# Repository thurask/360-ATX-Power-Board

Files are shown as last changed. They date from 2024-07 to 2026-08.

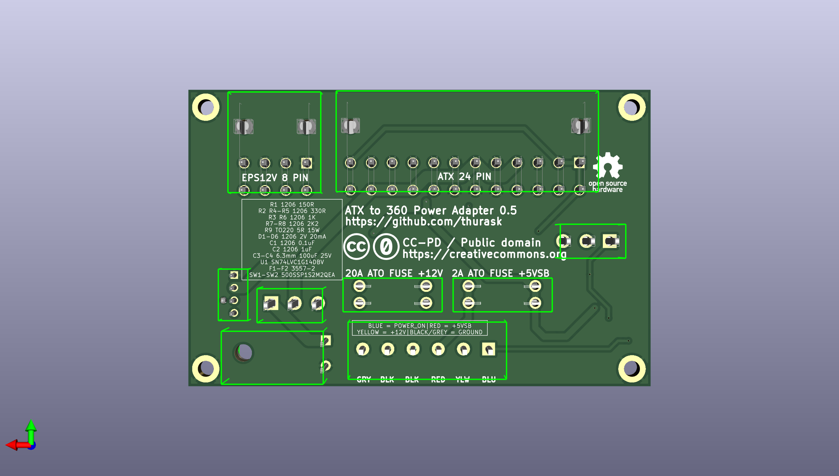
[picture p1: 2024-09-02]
360_atx_power_board_2.png

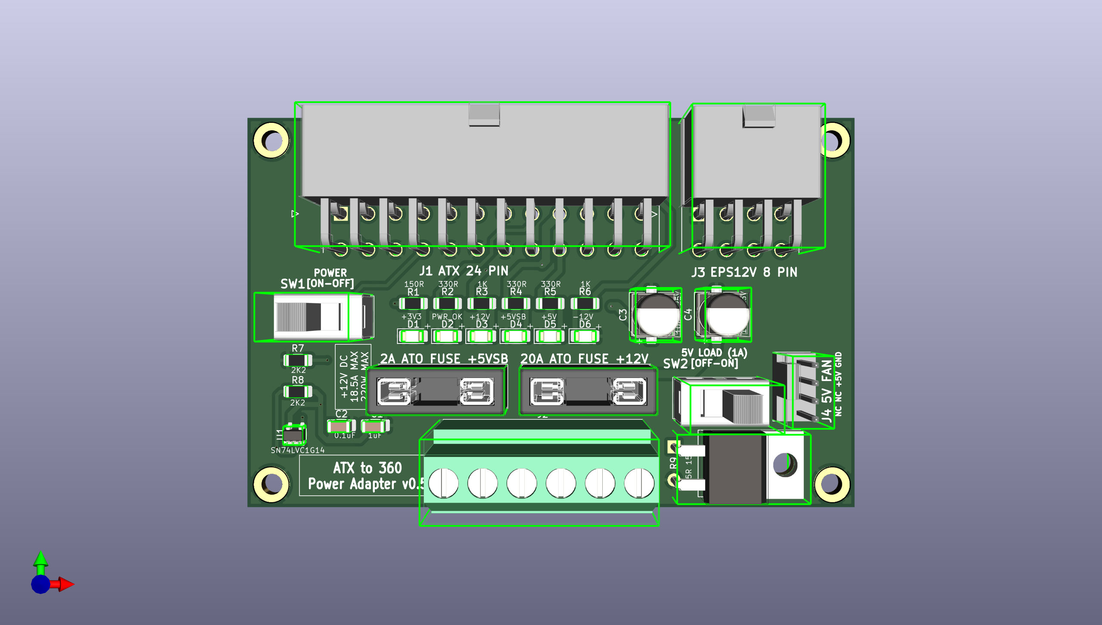
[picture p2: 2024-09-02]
360_atx_power_board.png

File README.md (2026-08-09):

# 360-ATX-Power-Board
ATX to Xbox power adapter board for Xbox 360

360_atx_power_board

# Rationale
Powering an Xbox 360 without using the original antique brick, instead using a modern, quiet, smaller, efficient ATX power supply. Also doing the same without just having components and wire connections dangling in air or stuck on breadboard.

# Compatibility
Any Xbox 360, provided you have some way of getting power from the screw terminals into the console itself. I tested this with a Xenon. The most power-hungry model (Xenon) came with a 203W power adapter, so a 300W or higher ATX PSU should power without running into current limits.

This theoretically could work with an Xbox One but I don't have one to test.

# Prerequisites
- An ATX power supply capable of supplying at least 220W over 12V
- The power cable from an Xbox 360 power brick or compatible replacement
- Fuses (automotive style ATO fuses), 2A and 20A

# Instructions
1. Desolder or otherwise harvest the device-side power cable (i.e. not the wall end) from an Xbox 360 power brick or compatible; I think you can get the connector itself on Aliexpress and fabricate your own cable with thick enough wiring to handle the current
2. Assemble PCB, including installing the fuses
3. Connect your power supply's 24 pin ATX connector and the 4/8 pin EPS12V connector to the PCB; the absolute maximum power draw for 20 pin ATX and 4 pin EPS12V is just barely enough (20A) to fully supply the most power-hungry Xbox, so ideally plug in 24 pins and 8 pins respectively
4. Connect the Xbox 360 power cable to screw terminal J2; wire colors should match markings on PCB silkscreen
   -   If you harvested a cable from a power brick, consider soldering appropriate gauge short extensions to each connector with solder seal connectors, and then crimping ferrules on the other end of the extensions so that it connects better to the screw terminals
5. Connect the other end of the Xbox 360 power cable to your console
6. Turn on your power supply; +5VSB LED (if installed) should light up
7. Set switch SW1 (if installed) to on
8. Turn on Xbox 360; all LEDs should light up, as should your Xbox

# Building the PCB
Import project files into KiCad 10 and export to your PCB manufacturing service of choice, or just use the files in the grbl subfolder. It's a four layer PCB and it'll carry quite a bit of current, so I recommend thicker than default copper.

# BOM
- Connectors
  - Input
    - J1: 24-pin ATX connector, Molex 39-30-1240 or compatible
    - J3: 8-pin EPS12V connector, Molex 39-30-1080 or compatible
  - Output
    - J2: Phoenix Contact MKDS 3/ 6-5,08 / 1905201 or any compatible 6 hole screw terminal that can handle maximum power draw (>=20A)
  - Fan connector
    - If you want to keep things cool there's a 4 pin PC fan plug J4 intended for a 5V fan, Molex 47053-1000 or compatible. Use some slim Noctua 5V fan or something.
- Components
  - Power signaling
    - Required to translate ATX PS_ON# into the 360's power on signal. The other outputs are purely passthrough.
    - R7, R8: 2.2K, 1206
    - U1: Texas Instruments SN74LVC1G14DBVR or compatible part
    - C1: 1uF 1206 25V
    - C2: 0.1uF 1206 25V
  - Switching
    - SW1: E-Switch 500SSP1S2M2QEA or compatible, or just bridge pin 1 and 2 to always have the board active.
  - Fuses
    - F1-F2: Keystone Electronics 3557-2 or compatible. Uses ATO/ATC automotive fuses.
  - Filtering:
    - C3-C4: 100uF 25V electrolytics, 6.3mm x 7.7mm footprint. Würth Elektronik 865080445010 or compatible.
  - Indicators
    - Optional blinkenlights to see if each power rail is working. Install the following resistor-LED pairs:
    - +12V
      - R3: 1K, 1206
      - D3: 20mW LED, 1206  
    - +5V
      - R5: 330R, 1206
      - D5: 20mW LED, 1206  
    - +5VSB
      - R4: 330R, 1206
      - D4: 20mW LED, 1206
    - +3.3V
      - R1: 150R, 1206
      - D1: 20mW LED, 1206
    - -12V
      - R6: 1K, 1206
      - D6: 20mW LED, 1206 (note the reversed orientation compared to the others!)
    - PWR_OK
      - R2: 330R, 1206
      - D2: 20mW LED, 1206
  - 5V Load
    - Since the 360 is almost exclusively 12V load, some PSUs may shut down prematurely due to lack of 5V load. If you have such a PSU or just want to play it safe, install the following to have a 5W (1A) load:
    - SW2: E-Switch 500SSP1S2M2QEA or compatible (or bridge pins 1 and 2 to always have the load active), same part as SW1
    - R9: 5R, TO220, >=15W (ex. Bourns PWR220T-20-5R00F)

# Contributing
Feel free to do what you like with this; build it, change it, fix it, sell it, whatever. If you do make improvements it'd be super cool to make those publicly available.

# License
CC0-1.0

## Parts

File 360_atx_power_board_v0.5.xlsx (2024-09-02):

Item # | *Designator | *Qty | Manufacturer | *Mfg Part # | Description / Value | *Package/Footprint | Type | Your Instructions / Notes
1 | J1 | 1 | Molex | 39-30-1240 | Connector Header Through Hole, Right Angle 24 position 0.165" (4.20mm) | 24POS | THT | 24 pin ATX power connector
2 | J2 | 1 | Phoenix Contact | MKDS 3/ 6-5,08 / 1701144 | 6 Position Wire to Board Terminal Block Horizontal with Board 0.200" (5.08mm) Through Hole | 5POS | THT | Substitutions: CUI TB009-508-06BE; CUI TB010-508-06BE; TE 282841-6; TE 282857-6; Phoenix Contact 1989405; Phoenix Contact 1730544
3 | J3 | 1 | Molex | 39-30-1080 | Connector Header Through Hole, Right Angle 8 position 0.165" (4.20mm) | 8POS | THT | 8 pin EPS12V connector
4 | J4 | 1 | Molex | 47053-1000 | Connector Header Through Hole 4 position 0.100" (2.54mm) | 4POS | THT | 4 pin PC fan connector
5 | U1 | 1 | Texas Instruments | SN74LVC1G14DBVR | Inverter IC 1 Channel Schmitt Trigger SOT-23-5 | SOT-23 | SMD | Subsitutions: Nexperia 74LVC1G14GV-Q100,1 ; Diodes Incorporated 74LVC1G14W5-7 ; onsemi NC7SZ14M5X
6 | R1 | 1 | Yageo | RC1206FR-07150RL | 150 Ohms ±1% 0.25W, 1/4W Chip Resistor 1206 (3216 Metric) Moisture Resistant Thick Film | 1206 | SMD | Substitutions: any 0.25W 1206/3216 resistor with same value
7 | R2, R4-R5 | 3 | Yageo | RC1206JR-07330RL | 330 Ohms ±1% 0.25W, 1/4W Chip Resistor 1206 (3216 Metric) Moisture Resistant Thick Film | 1206 | SMD | Substitutions: any 0.25W 1206/3216 resistor with same value
8 | R3, R6 | 2 | Yageo | RC1206FR-071KL | 1 kOhms ±1% 0.25W, 1/4W Chip Resistor 1206 (3216 Metric) Moisture Resistant Thick Film | 1206 | SMD | Substitutions: any 0.25W 1206/3216 resistor with same value
9 | R7-R8 | 2 | Yageo | RC1206FR-072K2L | 2.2 kOhms ±1% 0.25W, 1/4W Chip Resistor 1206 (3216 Metric) Moisture Resistant Thick Film | 1206 | SMD | Substitutions: any 0.25W 1206/3216 resistor with same value
10 | R9 | 1 | Bourns | PWR220T-20-5R00F | 5 Ohms ±1% 20W Through Hole Resistor TO-220-2, Variant Automotive AEC-Q200, Current Sense, Pulse Withstanding Thick Film | TO-220 | THT | Substitutions: Bourns PWR220T-20-5R00J; Vishay LTO030F5R000FTE3; Caddock MP930-5.00-1%
11 | C1 | 1 | Kemet | C1206C105M3RAC7800 | 1 µF ±10% 25V Ceramic Capacitor X7R 1206 (3216 Metric) | 1206 | SMD | Substitutions: any 25V X7R 1206 ceramic capacitor with same value
12 | C2 | 1 | Kemet | C1206C104K3RAC7800 | 0.1 µF ±10% 25V Ceramic Capacitor X7R 1206 (3216 Metric) | 1206 | SMD | Substitutions: any 25V X7R 1206 ceramic capacitor with same value
13 | C3-C4 | 2 | Wurth Elektronik | 865080445010 | 100 µF 25 V Aluminum Electrolytic Capacitors Radial, Can - SMD 2000 Hrs @ 105°C | 6.3mmx8mm | SMD | Substitutions: Nichicon UWT1E101MCL1GS; Rubycon 25TZV100M6.3X8; Nichicon UCD1V101MCL6GS
14 | D1-D6 | 6 | Wurth Elektronik | 156120VS75000 | Green 573nm LED Indication - Discrete 2V 1206 (3216 Metric) | 1206 | SMD | Substitutions: Lite-On LTST-C150KGKT; Dialight 598-8270-102F; Bivar SM1206GC-IL
15 | F1-F2 | 2 | Keystone Electronics | 3557 | Fuse Block 30 A 500V 1 Circuit Blade Through Hole | 4PIN | THT
16 | SW1-2 | 2 | E-Switch | 500SSP1S2M2QEA | Slide Switches 5A 150VAC or 28VDC On-None-ON SPDT | SPDT | THT | Substitutions: any E-Switch 500SSP1SxM2xEx or 500SSP3SxM2xEx

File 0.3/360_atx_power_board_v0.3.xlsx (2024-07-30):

Item # | *Designator | *Qty | Manufacturer | *Mfg Part # | Description / Value | *Package/Footprint | Type | Your Instructions / Notes
1 | J1 | 1 | Molex | 39-30-1240 | Connector Header Through Hole, Right Angle 24 position 0.165" (4.20mm) | 24POS | THT | 24 pin ATX power connector
2 | J2 | 1 | Phoenix Contact | MKDS 3/ 5-5,08 / 1905201 | 5 Position Wire to Board Terminal Block Horizontal with Board 0.200" (5.08mm) Through Hole | 5POS | THT | Substitutions: CUI TB009-508-05BE; CUI TB010-508-05BE; TE 282841-5; TE 282857-5; Phoenix Contact 1931644; Phoenix Contact 1730531
3 | J3 | 1 | TE | 641737-1 | Connector Header Through Hole, Right Angle 4 position 0.200" (5.08mm) | 4POS | THT | 4 pin "Molex" peripheral connector
4 | J4 | 1 | Molex | 39-30-1080 | Connector Header Through Hole, Right Angle 8 position 0.165" (4.20mm) | 8POS | THT | 8 pin EPS12V connector
5 | J5 | 1 | Molex | 45586-0005 | Connector Header Through Hole, Right Angle 8 position 0.165" (4.20mm) | 8POS | THT | 8 pin PCI Express connector
6 | Q1 | 1 | Diotec Semiconductor | MMBT3904 | Bipolar (BJT) Transistor NPN 40 V 200 mA 300MHz 350 mW Surface Mount SOT-23-3 (TO-236) | SOT-23 | SMD | Substitutions: any other manufacturer's MMBT3904
7 | R1 | 1 | Vishay | RCC1206150RFKEA | 150 Ohms ±1% 0.5W, 1/2W Chip Resistor 1206 (3216 Metric) Automotive AEC-Q200 Thick Film | 1206 | SMD | Substitutions: any 0.5W 1206/3216 resistor with same value
8 | R2, R4, R5 | 3 | Vishay | RCC1206330RFKEA | 330 Ohms ±1% 0.5W, 1/2W Chip Resistor 1206 (3216 Metric) Automotive AEC-Q200 Thick Film | 1206 | SMD | Substitutions: any 0.5W 1206/3216 resistor with same value
9 | R3, R8 | 2 | Vishay | RCC12061K00FKEA | 1 kOhms ±1% 0.5W, 1/2W Chip Resistor 1206 (3216 Metric) Automotive AEC-Q200 Thick Film | 1206 | SMD | Substitutions: any 0.5W 1206/3216 resistor with same value
10 | R6 | 1 | Vishay | RCC1206100KFKEA | 100 kOhms ±1% 0.5W, 1/2W Chip Resistor 1206 (3216 Metric) Automotive AEC-Q200 Thick Film | 1206 | SMD | Substitutions: any 0.5W 1206/3216 resistor with same value
11 | R7 | 1 | Bourns | PWR220T-20-2R50F | 2.5 Ohms ±1% 20W Through Hole Resistor TO-220-2, Variant Automotive AEC-Q200, Current Sense, Pulse Withstanding Thick Film | TO-220 | THT | Substitutions: Bourns PWR220T-35-2R50F; Vishay LTO030F2R500FTE3; Caddock MP930-2.50-1%
12 | D1-D6 | 6 | Wurth Elektronik | 156120VS75000 | Green 573nm LED Indication - Discrete 2V 1206 (3216 Metric) | 1206 | SMD | Substitutions: Lite-On LTST-C150KGKT; Dialight 598-8270-102F; Bivar SM1206GC-IL
13 | SW1-2 | 2 | E-Switch | 500SSP1S2M2QEA | Slide Switches 5A 150VAC or 28VDC On-None-ON SPDT | SPDT | THT | Substitutions: any E-Switch 500SSP1SxM2xEx or 500SSP3SxM2xEx

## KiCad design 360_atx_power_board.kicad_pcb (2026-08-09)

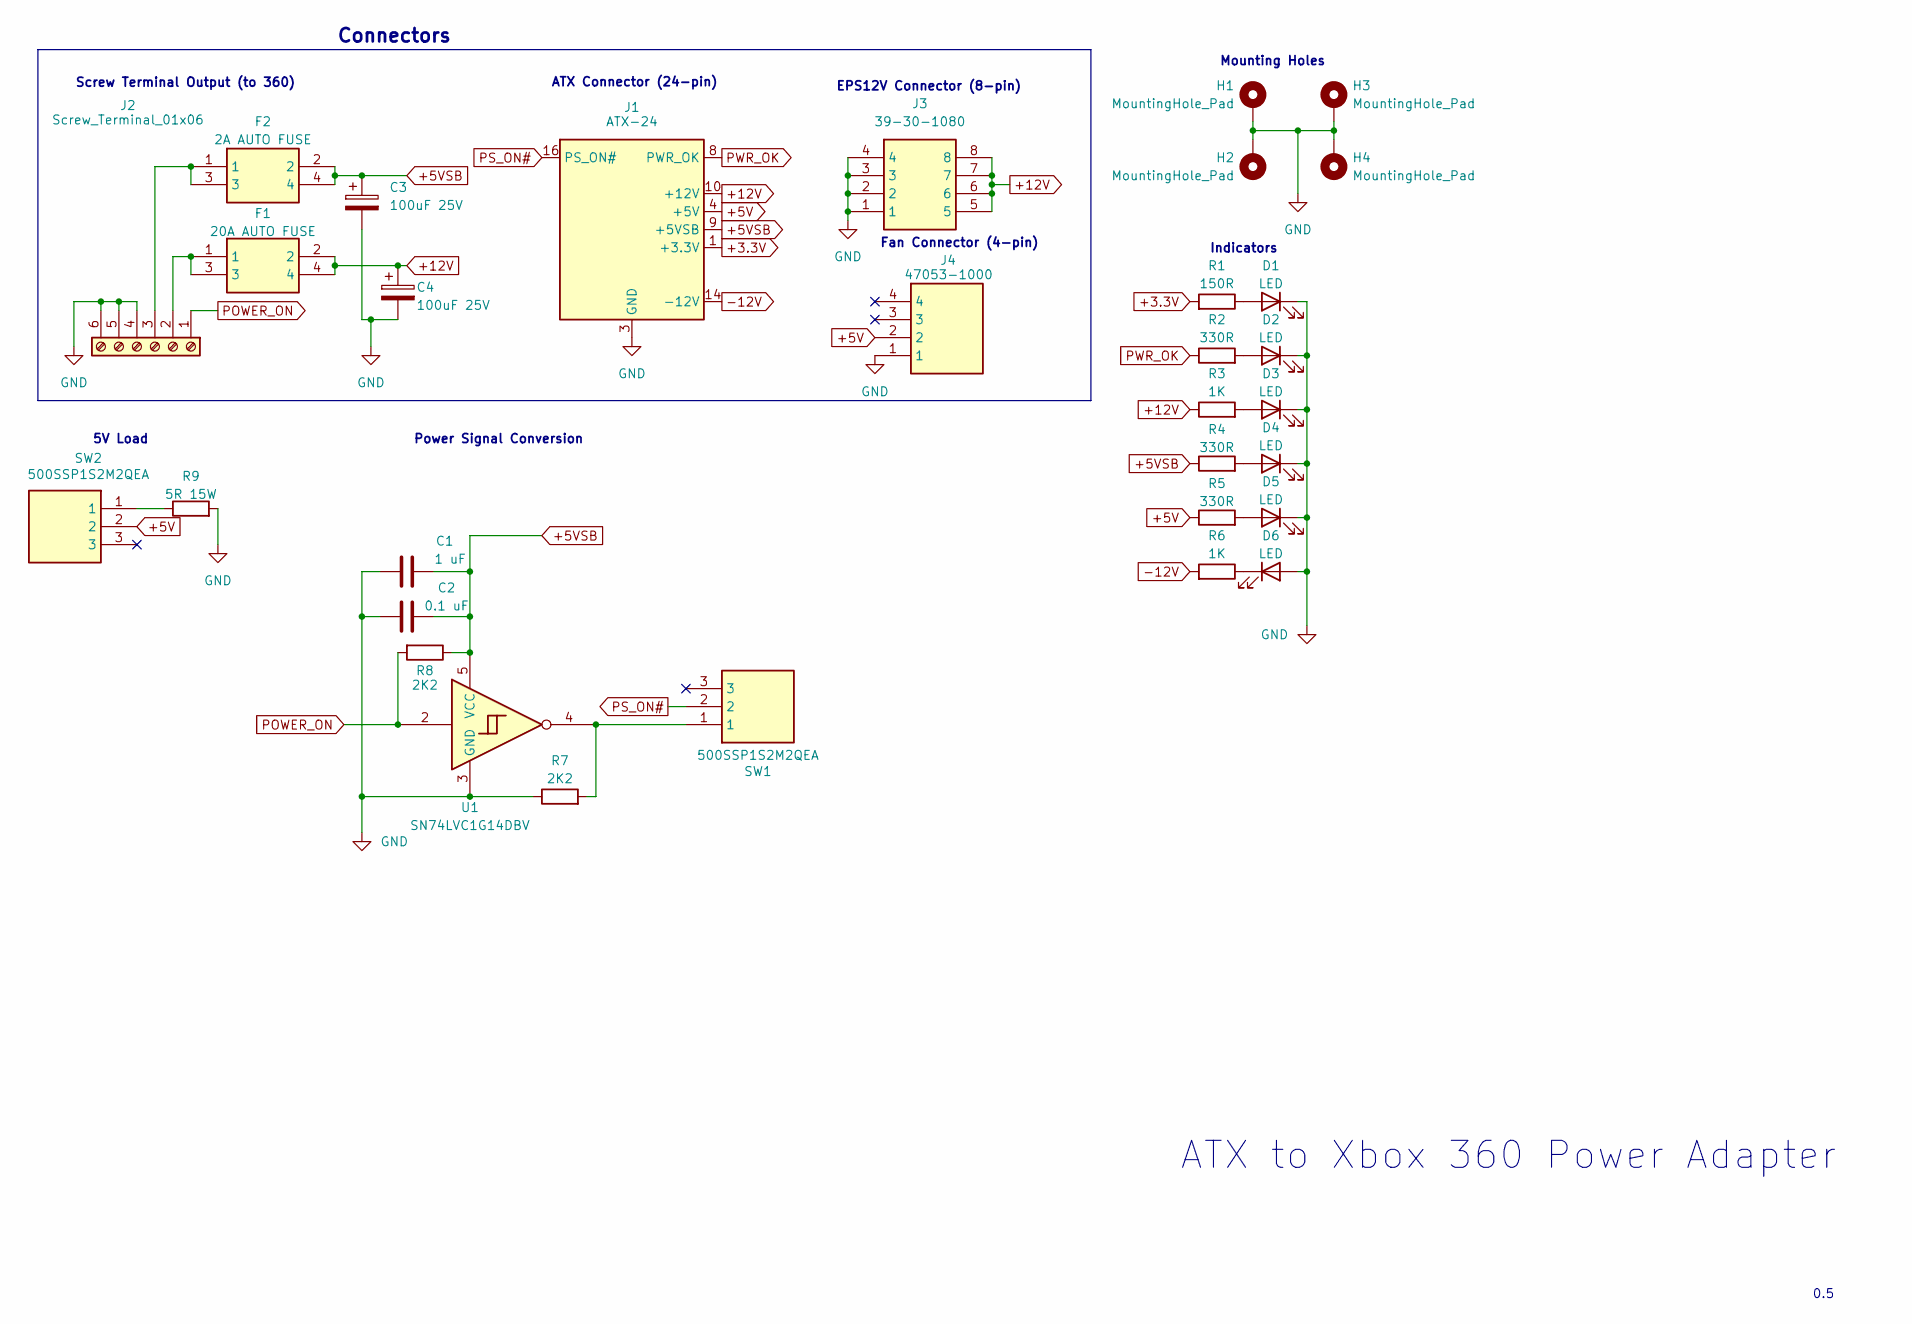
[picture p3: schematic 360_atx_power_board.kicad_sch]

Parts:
C1: 1 uF; C_1206_3216Metric_Pad1.33x1.80mm_HandSolder
C2: 0.1 uF; C_1206_3216Metric_Pad1.33x1.80mm_HandSolder
C3, C4: 100uF 25V; CP_Elec_6.3x7.7
D1, D2, D3, D4, D5, D6: LED; LED_1206_3216Metric_Pad1.42x1.75mm_HandSolder
F1: 20A AUTO FUSE; 3557-2; Manufacturer_Part_Number 3557-2; Mouser Part Number 534-3557-2
F2: 2A AUTO FUSE; 3557-2; Manufacturer_Part_Number 3557-2; Mouser Part Number 534-3557-2
H1, H2, H3, H4: MountingHole_Pad; MountingHole_3.2mm_M3_ISO14580_Pad
J1: ATX-24; 39-30-124Y_012
J2: Screw_Terminal_01x06; TerminalBlock_Phoenix_MKDS-3-6-5.08_1x06_P5.08mm_Horizontal
J3: 39-30-1080; 39-30-108Y_012; Mouser Part Number 538-39-30-1080
J4: 47053-1000; 470531000; Mouser Part Number 538-47053-1000
R1: 150R; R_1206_3216Metric_Pad1.30x1.75mm_HandSolder
R2, R4, R5: 330R; R_1206_3216Metric_Pad1.30x1.75mm_HandSolder
R3, R6: 1K; R_1206_3216Metric_Pad1.30x1.75mm_HandSolder
R7, R8: 2K2; R_1206_3216Metric_Pad1.30x1.75mm_HandSolder
R9: 5R 15W; TO-220-2_Horizontal_TabDown
SW1: 500SSP1S2M2QEA; Manufacturer_Part_Number 500SSP1S2M2QEA; Mouser Part Number 612-500SSP1S2M2QEA
SW2: 500SSP1S2M2QEA; Mouser Part Number 612-500SSP1S2M2QEA
U1: SN74LVC1G14DBV; SOT-23-5

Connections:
+3.3V: J1.1 (+3.3V), J1.2 (+3.3V), J1.12 (+3.3V), J1.13 (+3.3V), R1.2
+5V: J1.4 (+5V), J1.6 (+5V), J1.21 (+5V), J1.22 (+5V), J1.23 (+5V), J4.2, R5.1, SW2.2
+5VSB: C1.1, C2.1, C3.1, F2.2, F2.4, J1.9 (+5VSB), R4.1, R8.1, U1.5 (VCC)
+12V: C4.1, F1.2, F1.4, J1.10 (+12V), J1.11 (+12V), J3.5, J3.6, J3.7, J3.8, R3.1
-12V: J1.14 (-12V), R6.2
GND: C1.2, C2.2, C3.2, C4.2, D1.1 (K), D2.1 (K), D3.1 (K), D4.1 (K), D5.1 (K), D6.2 (A), H1.1 (1_1), H2.1 (1_1), H3.1 (1_1), H4.1 (1_1), J1.3 (GND), J1.5 (GND), J1.7 (GND), J1.15 (GND), J1.17 (GND), J1.18 (GND), J1.19 (GND), J1.24 (GND), J2.4, J2.5, J2.6, J3.1, J3.2, J3.3, J3.4, J4.1, R7.1, R9.2, U1.3 (GND)
unnamed: D1.2 (A), R1.1
unnamed: D2.2 (A), R2.2
unnamed: D3.2 (A), R3.2
unnamed: D4.2 (A), R4.2
unnamed: D5.2 (A), R5.2
unnamed: D6.1 (K), R6.1
unnamed: F1.1, F1.3, J2.2
unnamed: F2.1, F2.3, J2.3
unnamed: R7.2, SW1.1, U1.4
unnamed: R9.1, SW2.1
POWER_ON: J2.1, R8.2, U1.2
PS_ON#: J1.16 (PS_ON#), SW1.2
PWR_OK: J1.8 (PWR_OK), R2.1

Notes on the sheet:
5V Load
Indicators
Power Signal Conversion
Screw Terminal Output (to 360)
Connectors
ATX to Xbox 360 Power Adapter
0.5
EPS12V Connector (8-pin)
ATX Connector (24-pin)
Mounting Holes
Fan Connector (4-pin)

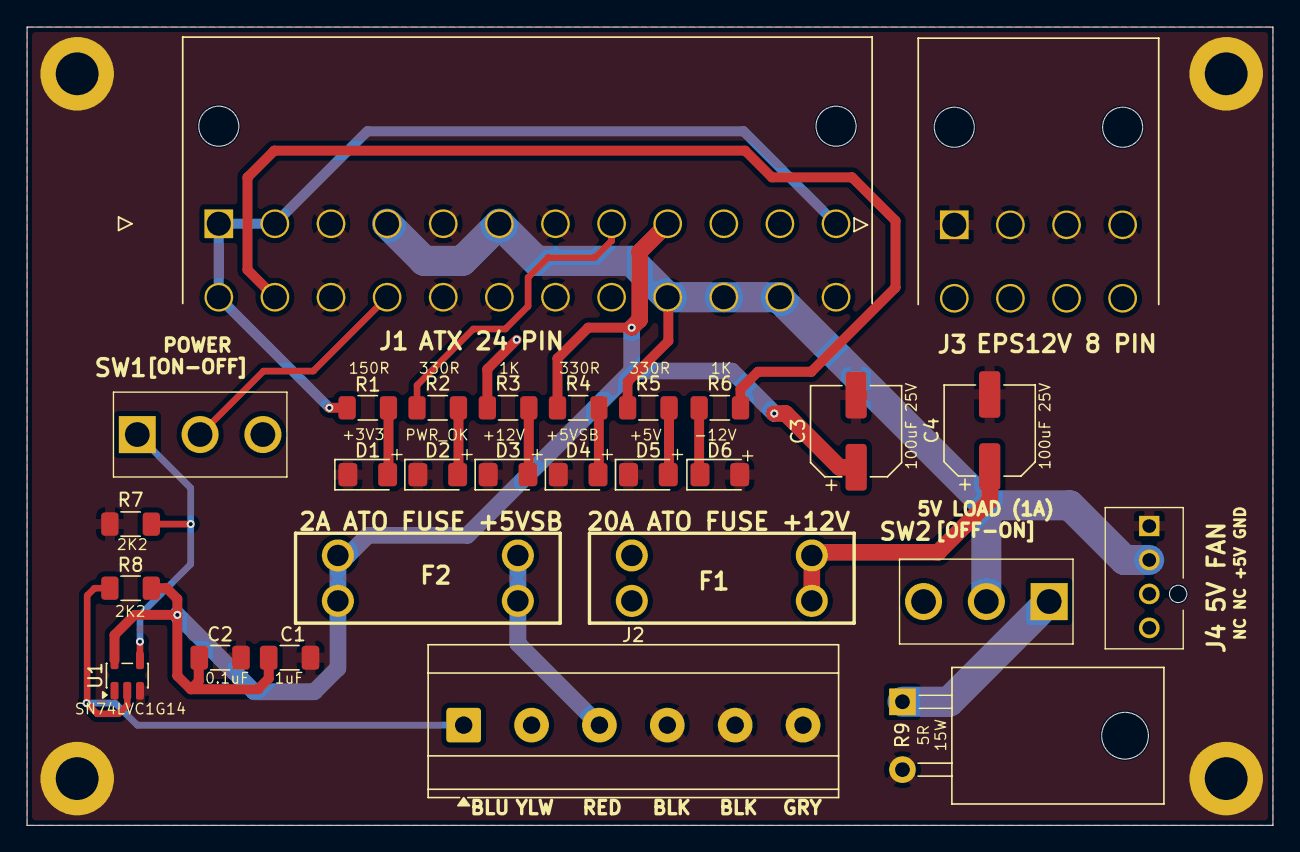
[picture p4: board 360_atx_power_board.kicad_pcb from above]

Board: 4 copper layers, 93.2 x 59.8 mm, 33 parts (1 on the bottom side), 19 nets.

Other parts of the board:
logo1: OSHW-Logo_7.5x8mm_SilkScreen

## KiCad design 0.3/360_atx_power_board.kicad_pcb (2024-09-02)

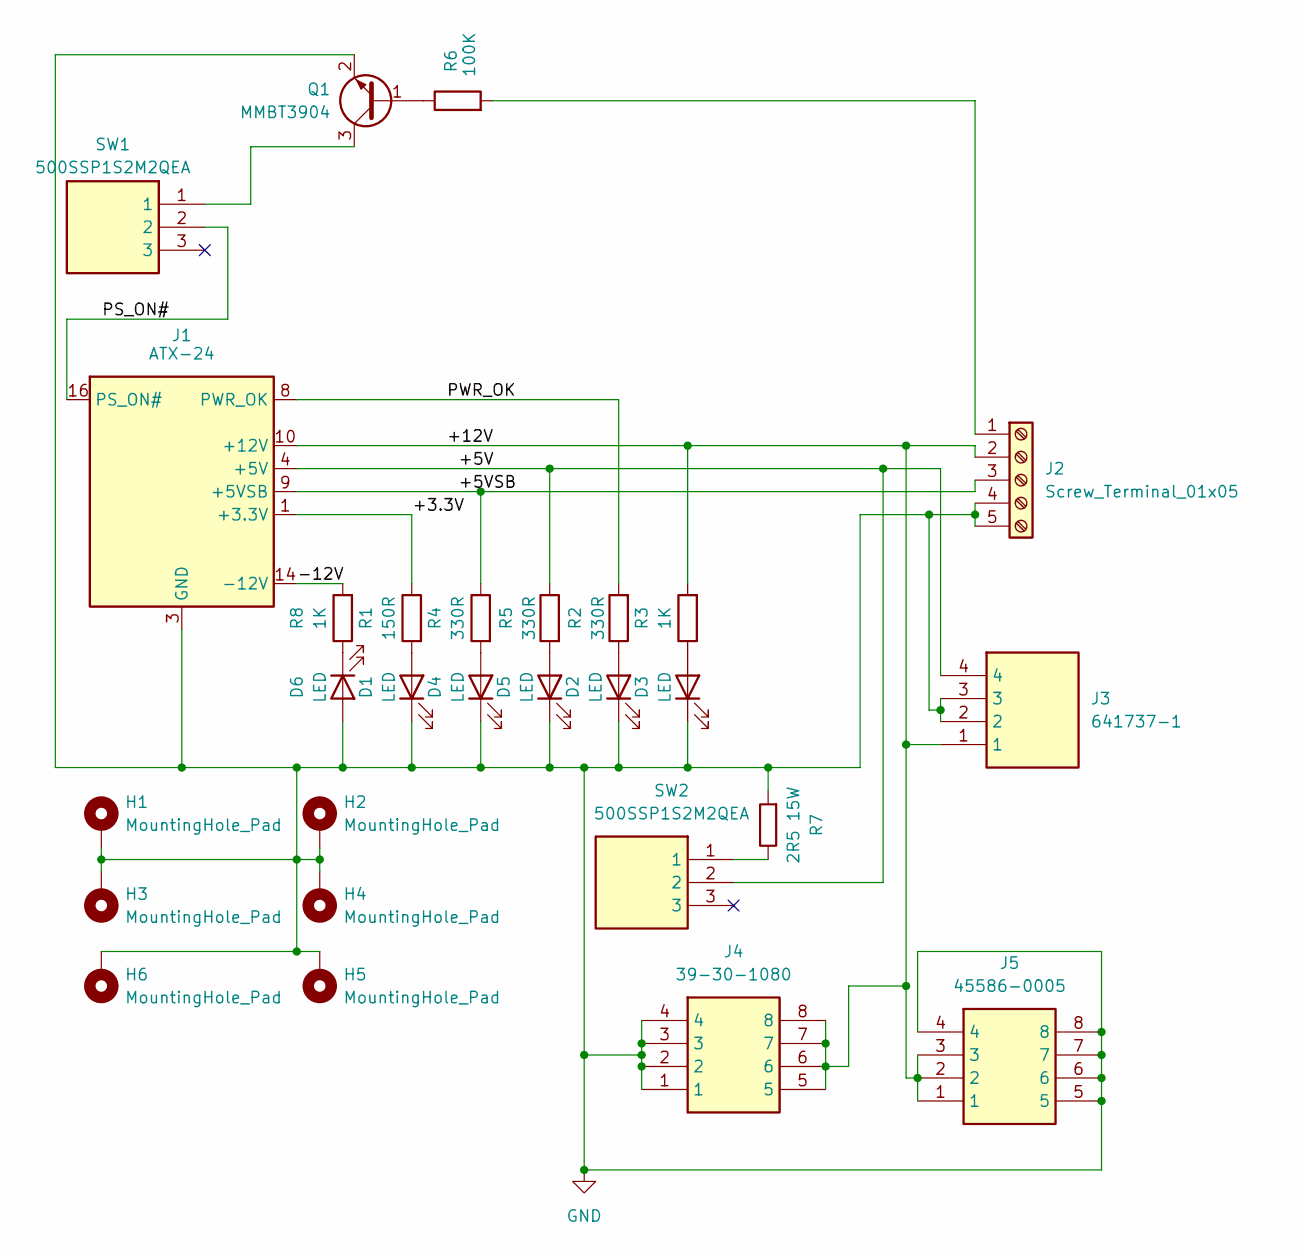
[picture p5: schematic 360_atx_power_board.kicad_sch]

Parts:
D1, D2, D3, D4, D5, D6: LED; LED_1206_3216Metric_Pad1.42x1.75mm_HandSolder
H1, H2, H3, H4, H5, H6: MountingHole_Pad; MountingHole_3.2mm_M3_ISO14580_Pad
J1: ATX-24; 39-30-124Y_012
J2: Screw_Terminal_01x05; TerminalBlock_Phoenix_MKDS-3-5-5.08_1x05_P5.08mm_Horizontal
J3: 641737-1; Mouser Part Number 571-6417371
J4: 39-30-1080; 39-30-108Y_012; Mouser Part Number 538-39-30-1080
J5: 45586-0005; 45586-000Y; Manufacturer_Part_Number 45586-0005; Mouser Part Number 538-45586-0005
Q1: MMBT3904; SOT-23_BigPads
R1: 150R; R_1206_3216Metric_Pad1.30x1.75mm_HandSolder
R2, R4, R5: 330R; R_1206_3216Metric_Pad1.30x1.75mm_HandSolder
R3, R8: 1K; R_1206_3216Metric_Pad1.30x1.75mm_HandSolder
R6: 100K; R_1206_3216Metric_Pad1.30x1.75mm_HandSolder
R7: 2R5 15W; TO-220-2_Horizontal_TabDown
SW1: 500SSP1S2M2QEA; Manufacturer_Part_Number 500SSP1S2M2QEA; Mouser Part Number 612-500SSP1S2M2QEA
SW2: 500SSP1S2M2QEA; Mouser Part Number 612-500SSP1S2M2QEA

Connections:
/+3.3V: J1.1 (+3.3V), J1.2 (+3.3V), J1.12 (+3.3V), J1.13 (+3.3V), R1.1
/+5V: J1.4 (+5V), J1.6 (+5V), J1.21 (+5V), J1.22 (+5V), J1.23 (+5V), J3.4, R5.1, SW2.2
/+5VSB: J1.9 (+5VSB), J2.3, R4.1
/+12V: J1.10 (+12V), J1.11 (+12V), J2.2, J3.1, J4.5, J4.6, J4.7, J4.8, J5.1, J5.2, J5.3, R3.2
/-12V: J1.14 (-12V), R8.2
/PS_ON#: J1.16 (PS_ON#), SW1.2
/PWR_OK: J1.8 (PWR_OK), R2.2
GND: D1.1 (K), D2.1 (K), D3.1 (K), D4.1 (K), D5.1 (K), D6.2 (A), H1.1, H2.1, H3.1, H4.1, H5.1, H6.1, J1.3 (GND), J1.5 (GND), J1.7 (GND), J1.15 (GND), J1.17 (GND), J1.18 (GND), J1.19 (GND), J1.24 (GND), J2.4, J2.5, J3.2, J3.3, J4.1, J4.2, J4.3, J4.4, J5.4, J5.5, J5.6, J5.7, J5.8, Q1.2 (E), R7.1
unnamed: D1.2 (A), R1.2
unnamed: D2.2 (A), R2.1
unnamed: D3.2 (A), R3.1
unnamed: D4.2 (A), R4.2
unnamed: D5.2 (A), R5.2
unnamed: D6.1 (K), R8.1
unnamed: J2.1, R6.2
unnamed: Q1.1 (B), R6.1
unnamed: Q1.3 (C), SW1.1
unnamed: R7.2, SW2.1

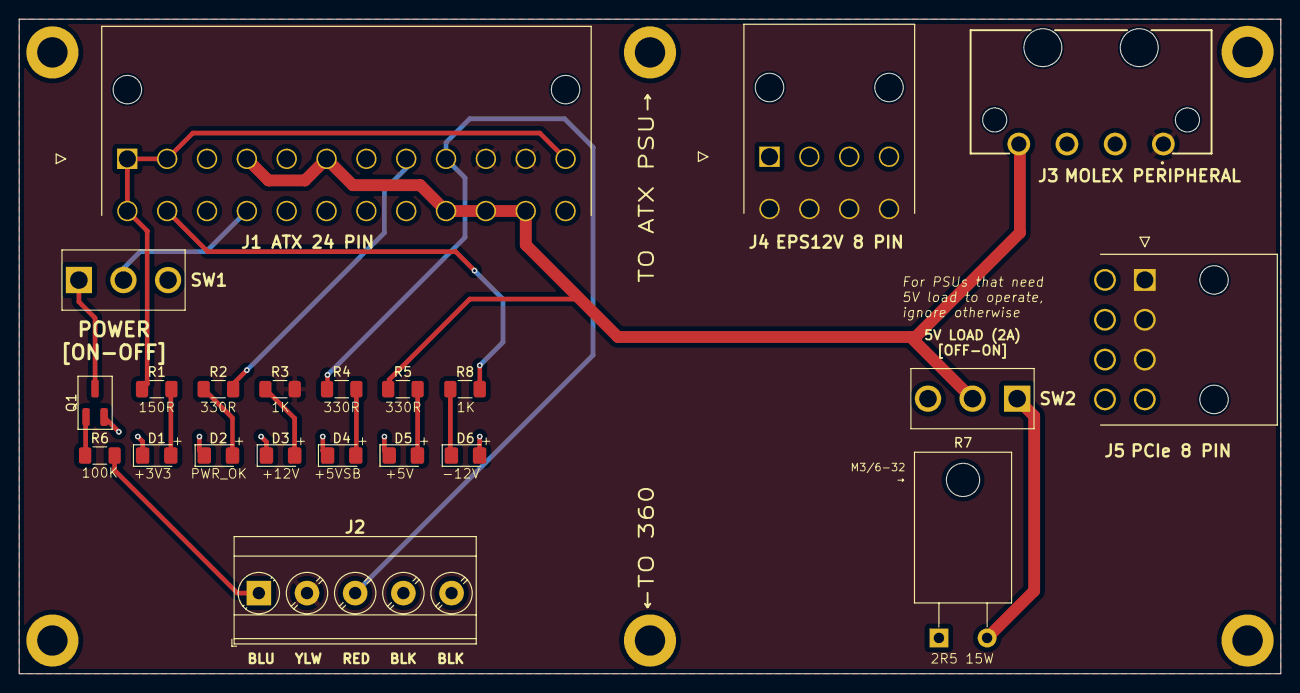
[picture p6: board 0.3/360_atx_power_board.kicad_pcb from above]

Board: 2 copper layers, 133.0 x 69.0 mm, 28 parts (0 on the bottom side), 18 nets.

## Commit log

2024-09-02 pcb rev 0.5
    [360_atx_power_board-B_Cu.gbr, 360_atx_power_board-B_Mask.gbr, 360_atx_power_board-B_Paste.gbr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]
2024-09-02 version 0.5 followup
    [360_atx_power_board-B_Cu.gbr, 360_atx_power_board-B_Mask.gbr, 360_atx_power_board-B_Paste.gbr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]
2026-08-09 kicad 10
    [360_atx_power_board-B_Cu.gbr, 360_atx_power_board-B_Mask.gbr, 360_atx_power_board-B_Paste.gbr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]
2026-08-09 untracked files, readme
    [360_atx_power_board-NPTH-drl_map.gbr, 360_atx_power_board-PTH-drl_map.gbr, 360_atx_power_board-job.gbrjob]

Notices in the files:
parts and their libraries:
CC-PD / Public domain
